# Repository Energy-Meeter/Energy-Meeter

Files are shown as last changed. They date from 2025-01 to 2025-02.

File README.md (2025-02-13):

# Energy Meeter

An esp32-powered smart plug and online dashboard.

## Features

- Online dashboard
- WiFi communication
- Capable of analyzing the power consumption of an arbitrary load
- 5A current rating

## Hardware

### Board Revision A

Status: Testing

The current revision of the energy meeter. We just received it from PCBWay, and we're now in the process of assembling and validating it.

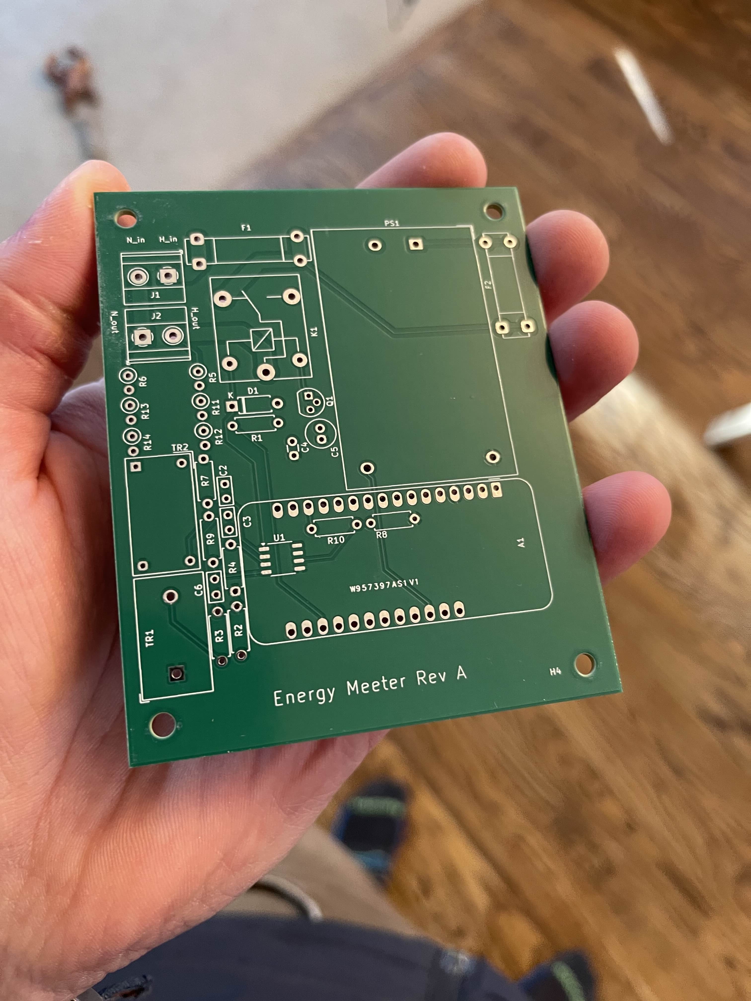
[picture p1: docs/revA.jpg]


#### Schematic
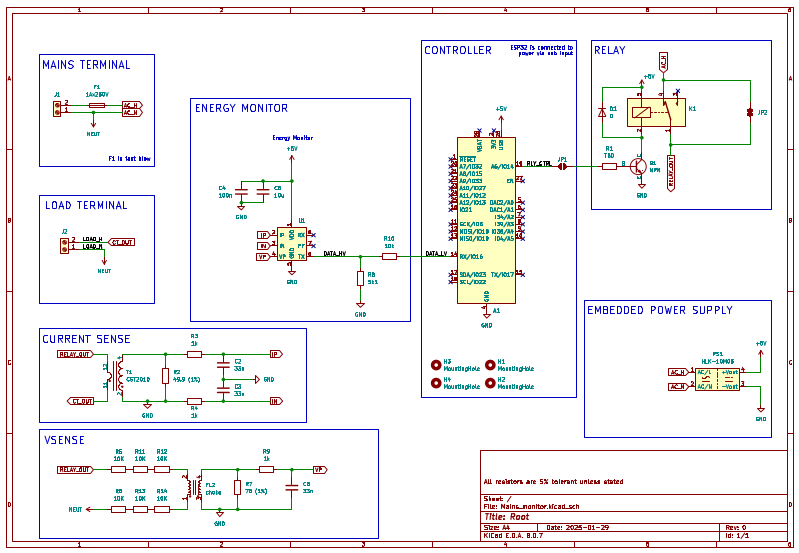
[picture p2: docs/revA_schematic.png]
schmatic


#### Board
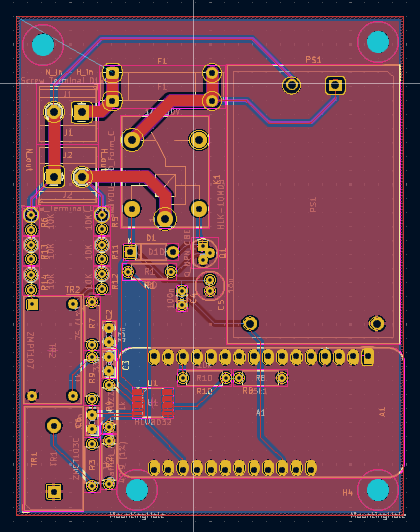
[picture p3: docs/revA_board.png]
board


#### Stack Up
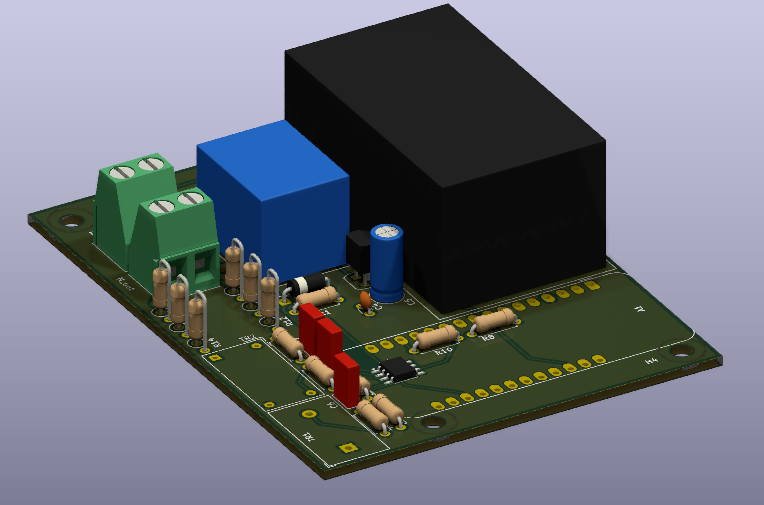
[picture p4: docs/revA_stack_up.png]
Stack up


## Software

### Networking and Dashboard

### Energy Monitor Library

- [HLW8032 energy monitor library](https://github.com/Energy-Meeter/HLW8032)

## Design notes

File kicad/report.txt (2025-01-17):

Plotted to '/home/cullen/Projects/Mains_monitor/kicad/Mains_monitor-energy monitor-Untitled Sheet.svg'.
Info: Done

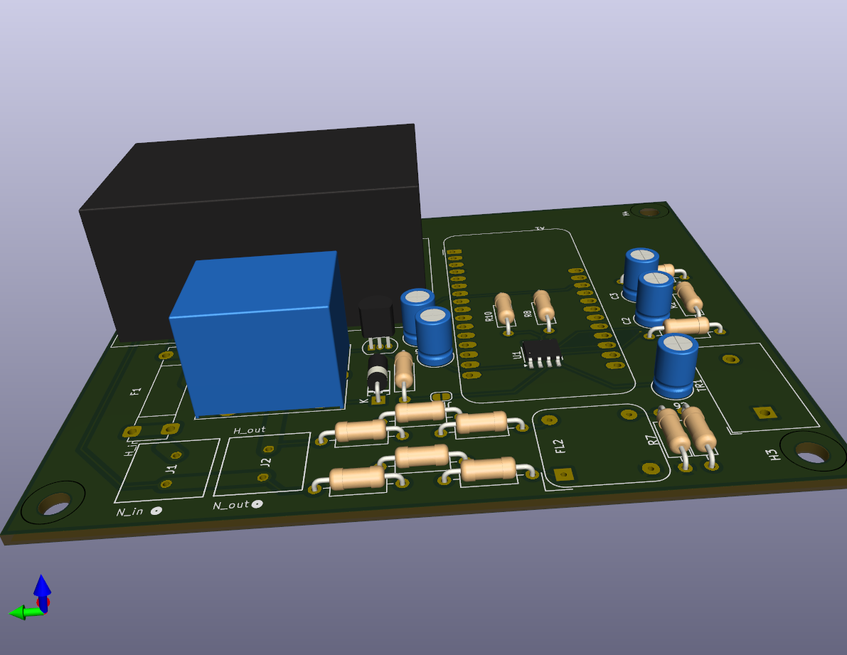
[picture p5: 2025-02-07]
kicad/Mains_monitor.png

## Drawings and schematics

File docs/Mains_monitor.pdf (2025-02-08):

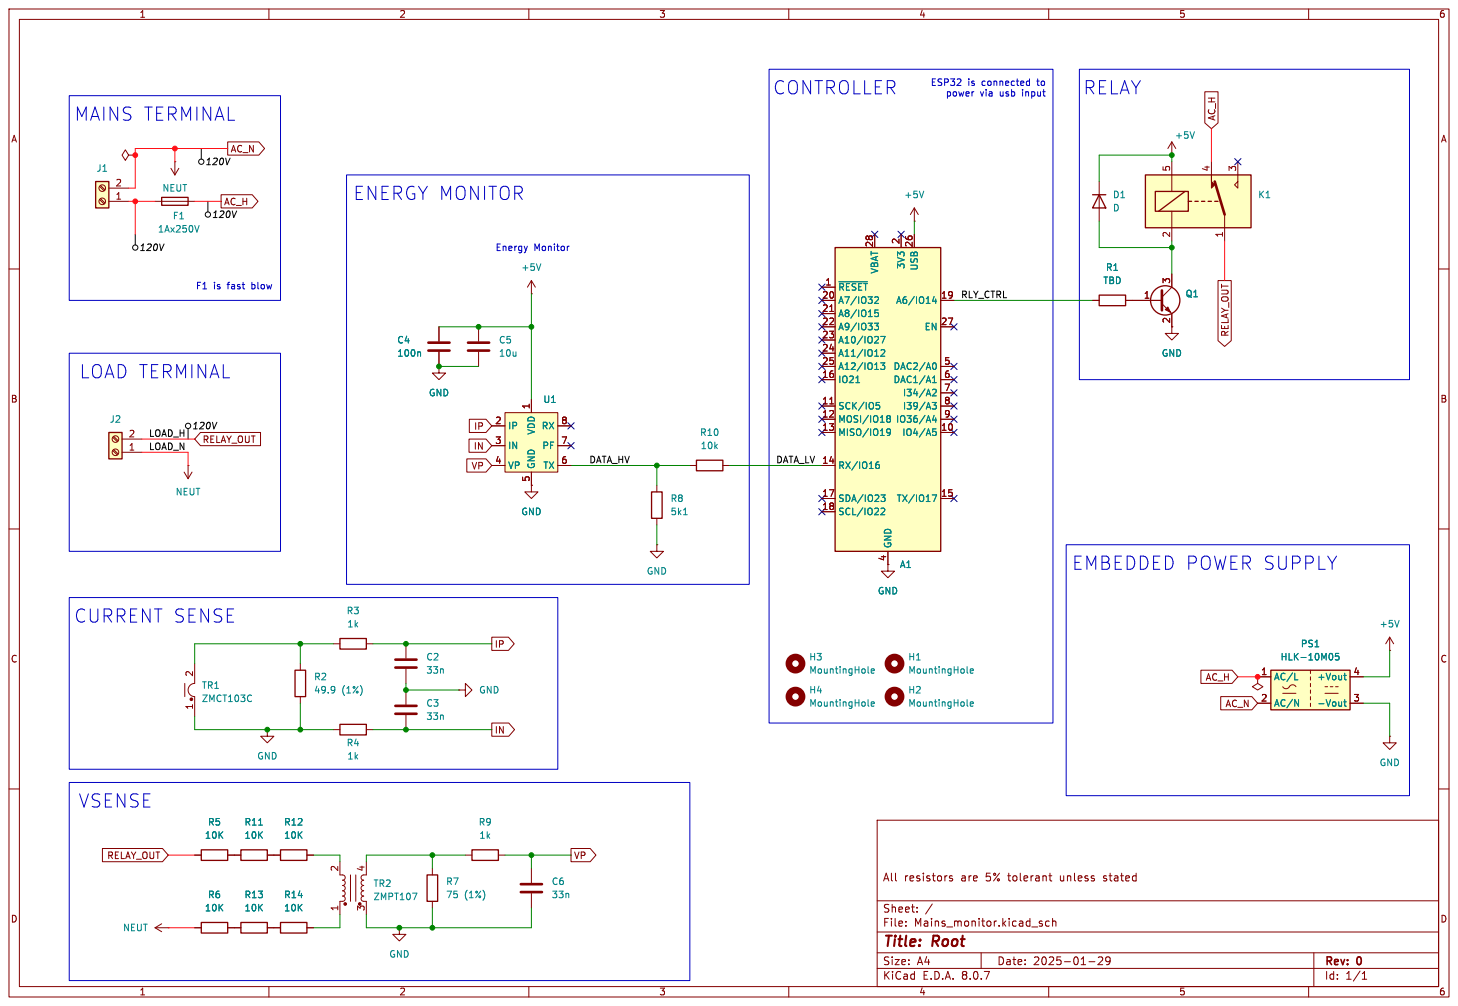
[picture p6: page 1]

power via usb input A1 ~{RESET} 1

2 A7/IO32 20 A8/IO15 21 A9/IO33 22 A10/IO27 23 A11/IO12 24 A12/IO13 25 USB 26 EN 27 VBAT 28 GND

F1 is fast blow LOAD TERMINAL

5 TX 6 PF 7 RX 8 U1 GND

5 TX 6 PF 7 RX 8 PS1 HLK-10M05 AC/L 1 AC/N 2

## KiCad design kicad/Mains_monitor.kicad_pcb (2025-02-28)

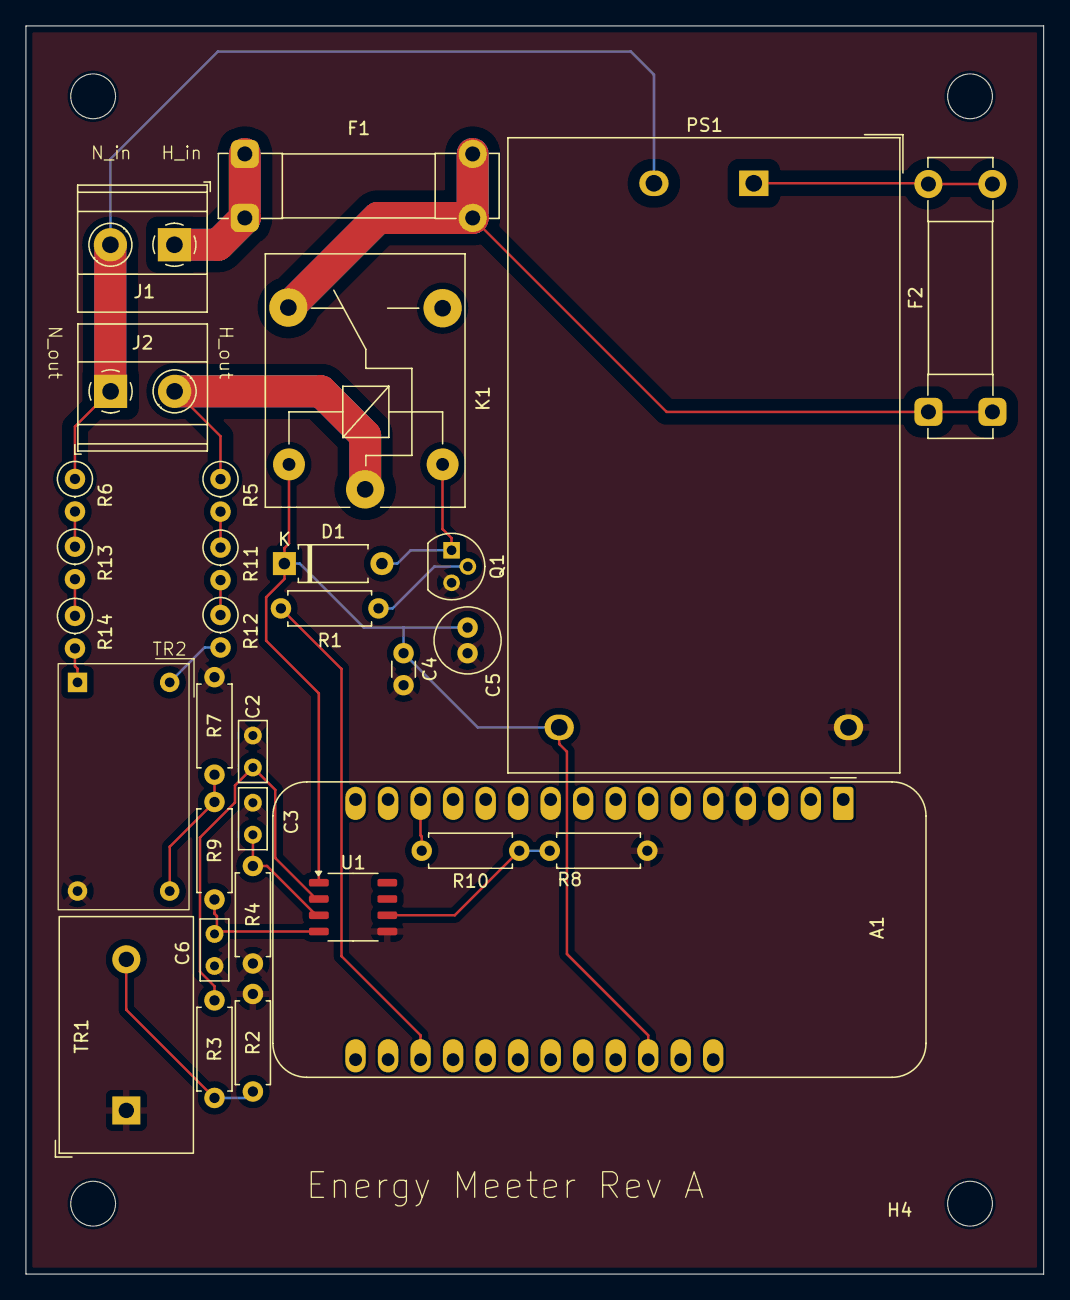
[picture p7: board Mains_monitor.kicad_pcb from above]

Board: 2 copper layers, 79.5 x 97.5 mm, 35 parts (0 on the bottom side), 23 nets.

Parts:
A1: Adafruit_Feather_HUZZAH32_ESP32; Adafruit_Feather
C2, C3, C6: 33n; C_Rect_L4.6mm_W2.0mm_P2.50mm_MKS02_FKP02
C4: 100n; C_Disc_D3.0mm_W1.6mm_P2.50mm
C5: 10u; C_Radial_D5.0mm_H11.0mm_P2.00mm
D1: D; D_A-405_P7.62mm_Horizontal
F1: 1Ax250V; Fuseholder_Clip-5x20mm_Bel_FC-203-22_Lateral_P17.80x5.00mm_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
F2: 100mAx250V; Fuseholder_Clip-5x20mm_Bel_FC-203-22_Lateral_P17.80x5.00mm_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
H1, H2, H3, H4: MountingHole; MountingHole_3.5mm
J1, J2: Screw_Terminal_01x02; TerminalBlock_Phoenix_MKDS-1,5-2_1x02_P5.00mm_Horizontal
K1: SANYOU_SRD_Form_C; Relay_SPDT_SANYOU_SRD_Series_Form_C
PS1: HLK-10M05; Converter_ACDC_Hi-Link_HLK-10Mxx
Q1: Q_NPN_CBE; TO-92
R1: TBD; R_Axial_DIN0207_L6.3mm_D2.5mm_P7.62mm_Horizontal
R2: 49.9 (1%); R_Axial_DIN0207_L6.3mm_D2.5mm_P7.62mm_Horizontal
R3, R4, R9: 1k; R_Axial_DIN0207_L6.3mm_D2.5mm_P7.62mm_Horizontal
R5, R6, R11, R12, R13, R14: 10K; R_Axial_DIN0207_L6.3mm_D2.5mm_P2.54mm_Vertical
R7: 75 (1%); R_Axial_DIN0207_L6.3mm_D2.5mm_P7.62mm_Horizontal
R8: 5k1; R_Axial_DIN0207_L6.3mm_D2.5mm_P7.62mm_Horizontal
R10: 10k; R_Axial_DIN0207_L6.3mm_D2.5mm_P7.62mm_Horizontal
TR1: ZMCT103C; Transformer_Zeming_ZMCT103C
TR2: ZMPT107; ZMPT107-1
U1: HLW8032; SSOP-8_3.9x5.05mm_P1.27mm

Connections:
+5V: A1.26 (USB), C4.1, C5.2, D1.1 (K), K1.5, PS1.4 (+Vout), U1.1 (VDD)
/DATA_HV: R8.1, R10.1, U1.6 (TX)
/DATA_LV: A1.14 (RX/IO16), R10.2
/RLY_CTRL: A1.19 (A6/IO14), R1.1
AC_H: F1.2, F2.1, K1.4
AC_N: J1.2, J2.1, PS1.2 (AC/N), R6.1
GND: A1.4 (GND), C2.2, C3.1, C4.2, C5.1, C6.2, PS1.3 (-Vout), Q1.3 (E), R2.2, R4.1, R7.1, R8.2, TR1.1, TR2.3, U1.5 (GND)
IN: C3.2, R4.2, U1.3 (IN)
IP: C2.1, R3.2, U1.2 (IP)
unnamed: D1.2 (A), K1.2, Q1.1 (C)
unnamed: F1.1, J1.1
unnamed: F2.2, PS1.1 (AC/L)
unnamed: Q1.2 (B), R1.2
unnamed: R2.1, R3.1, TR1.2
unnamed: R7.2, R9.1, TR2.4
unnamed: R5.2, R11.1
unnamed: R11.2, R12.1
unnamed: R12.2, TR2.2
unnamed: R6.2, R13.1
unnamed: R13.2, R14.1
unnamed: R14.2, TR2.1
RELAY_OUT: J2.2, K1.1, R5.1
VP: C6.1, R9.2, U1.4 (VP)

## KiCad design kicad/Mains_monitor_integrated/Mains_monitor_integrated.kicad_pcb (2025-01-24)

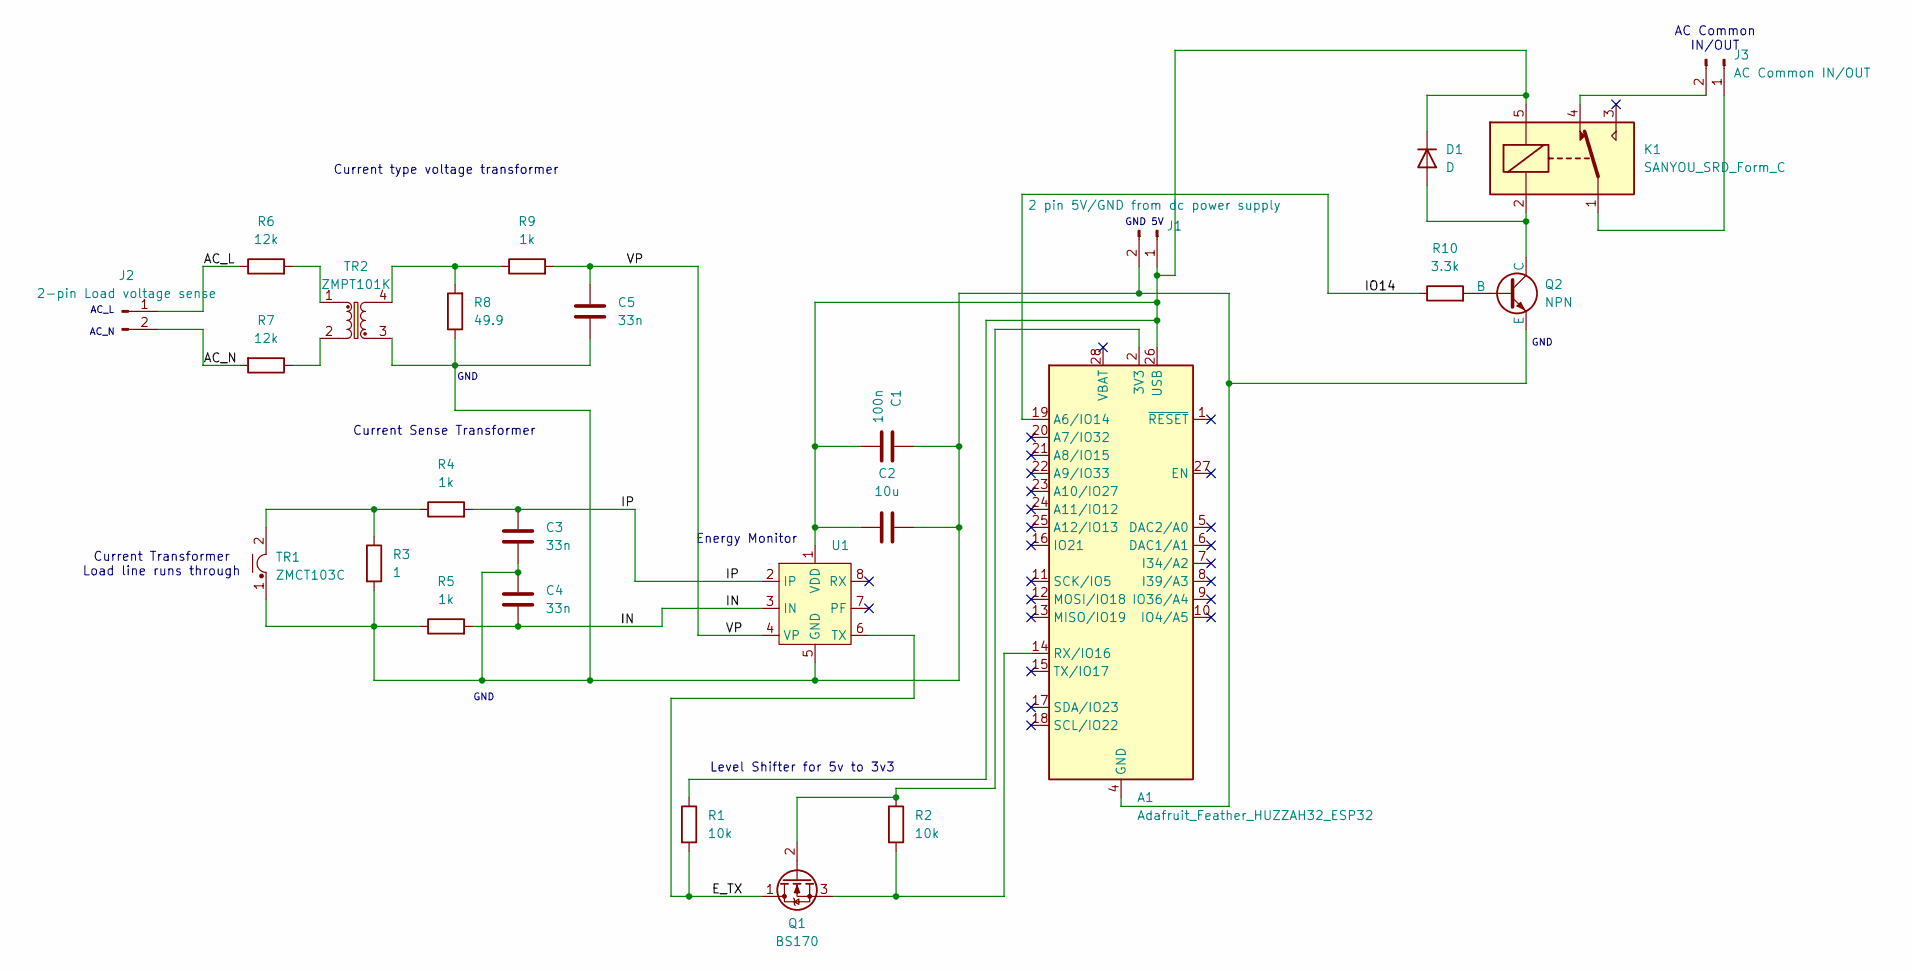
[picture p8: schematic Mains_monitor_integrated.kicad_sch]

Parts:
A1: Adafruit_Feather_HUZZAH32_ESP32; Adafruit_Feather
C1: 100n; C_0805_2012Metric_Pad1.18x1.45mm_HandSolder
C2: 10u; C_0805_2012Metric_Pad1.18x1.45mm_HandSolder
C3, C4, C5: 33n; C_0805_2012Metric_Pad1.18x1.45mm_HandSolder
D1: D; D_5W_P10.16mm_Horizontal
J1: 2 pin 5V/GND from dc power supply; PinSocket_1x02_P2.54mm_Vertical
J2: 2-pin Load voltage sense; PinHeader_1x02_P2.54mm_Vertical
J3: AC Common IN/OUT; PinHeader_1x02_P2.54mm_Vertical
K1: SANYOU_SRD_Form_C; Relay_SPDT_SANYOU_SRD_Series_Form_C
Q1: BS170; TO-92_Inline
Q2: NPN; TO-92_Inline
R1, R2: 10k; R_Axial_DIN0414_L11.9mm_D4.5mm_P5.08mm_Vertical
R3: 1; R_Axial_DIN0414_L11.9mm_D4.5mm_P5.08mm_Vertical
R4, R5, R9: 1k; R_Axial_DIN0414_L11.9mm_D4.5mm_P5.08mm_Vertical
R6, R7: 12k; R_Axial_DIN0414_L11.9mm_D4.5mm_P5.08mm_Vertical
R8: 49.9; R_Axial_DIN0414_L11.9mm_D4.5mm_P5.08mm_Vertical
R10: 3.3k; R_Axial_DIN0414_L11.9mm_D4.5mm_P5.08mm_Vertical
TR1: ZMCT103C; Transformer_Zeming_ZMCT103C
TR2: ZMPT101K; Transformer_Zeming_ZMPT101K
U1: HLW8032; SSOP-8_3.9x5.05mm_P1.27mm

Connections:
/AC_L: J2.1, R6.1
/AC_N: J2.2, R7.2
/E_TX: Q1.1 (D), R1.2, U1.6 (TX)
/IN: C4.2, R5.2, U1.3 (IN)
/IO14: A1.19 (A6/IO14), R10.1
/IP: C3.1, R4.2, U1.2 (IP)
/VP: C5.1, R9.2, U1.4 (VP)
unnamed: A1.2 (3V3), Q1.2 (G), R2.1
unnamed: A1.4 (GND), C1.1, C2.1, C3.2, C4.1, C5.2, J1.2, Q2.3 (E), R3.2, R5.1, R8.1, TR1.1, TR2.3, U1.5 (GND)
unnamed: A1.14 (RX/IO16), Q1.3 (S), R2.2
unnamed: A1.26 (USB), C1.2, C2.2, D1.1 (K), J1.1, K1.5, R1.1, U1.1 (VDD)
unnamed: D1.2 (A), K1.2, Q2.1 (C)
unnamed: J3.1, K1.1
unnamed: J3.2, K1.4
unnamed: Q2.2 (B), R10.2
unnamed: R3.1, R4.1, TR1.2
unnamed: R6.2, TR2.1
unnamed: R7.1, TR2.2
unnamed: R8.2, R9.1, TR2.4

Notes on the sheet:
GND
AC_L AC_N
Level Shifter for 5v to 3v3
AC Common IN/OUT
Current Sense Transformer
GND 5V
Current type voltage transformer
Energy Monitor
Current Transformer Load line runs through

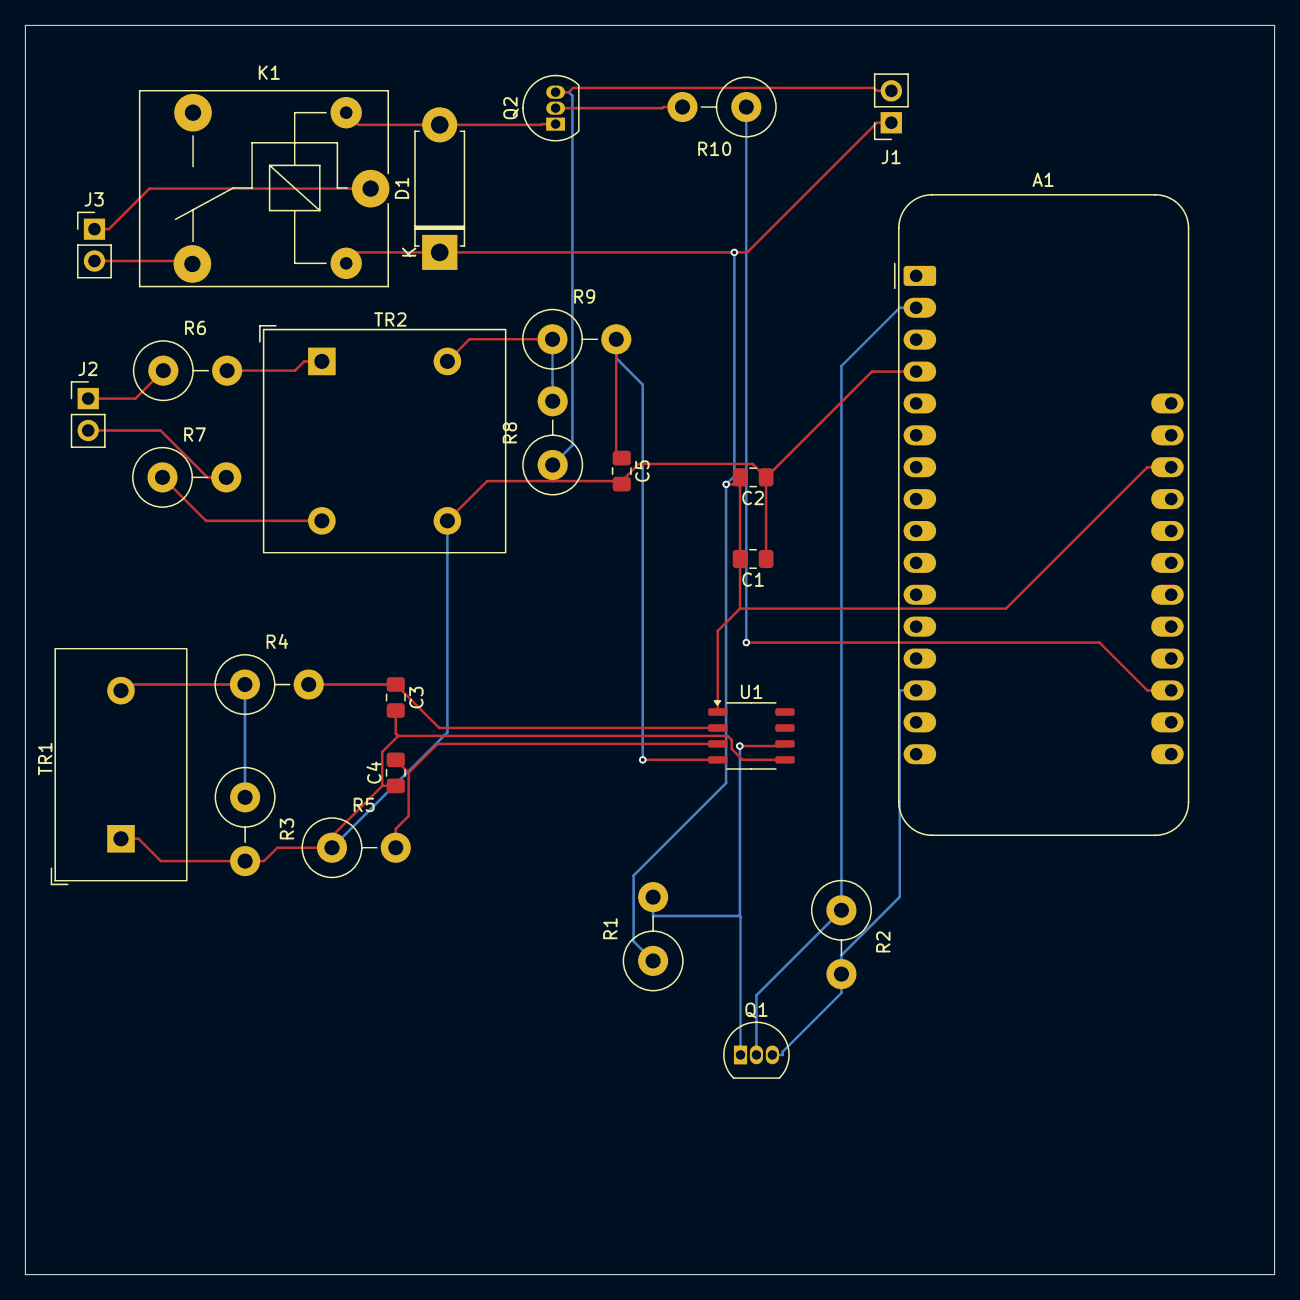
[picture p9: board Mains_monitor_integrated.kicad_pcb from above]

Board: 2 copper layers, 99.5 x 99.5 mm, 26 parts (0 on the bottom side), 19 nets.

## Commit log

2025-01-01 Init commit
    [Mains_monitor.kicad_pcb, Mains_monitor.kicad_sch, energy_monitor.kicad_sch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]
2025-01-01 Design power supply circuit
    [Mains_monitor.kicad_sch, current_sense_ckt.kicad_sch, energy_monitor.kicad_sch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]
2025-01-17 Add rev0 schematic
    [current_sense_ckt.kicad_sch, energy_monitor.kicad_sch, isolated supply.kicad_sch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]
2025-01-17 Add pdf of rev0 schematic
2025-01-19 Add git ignore for KiCad Projectt
2025-01-19 Consolidate schematic to a single sheet
    [current_sense_ckt.kicad_sch, energy_monitor.kicad_sch, isolated supply.kicad_sch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]
2025-01-24 created new schematic to integrate all components into a fully connected final version
    [Mains_monitor_integrated.kicad_pcb, Mains_monitor_integrated.kicad_sch]
2025-01-24 completed rough schematic and built first prototype pcb
    [Mains_monitor_integrated.kicad_pcb, Mains_monitor_integrated.kicad_sch]
2025-01-31 Improve sch clarity
    [Mains_monitor.kicad_sch]
2025-02-03 added footprints for all components, started PCB layout
    [Mains_monitor.kicad_pcb, Mains_monitor.kicad_sch]
2025-02-03 added mounting holes and ground layers
    [Mains_monitor.kicad_pcb, Mains_monitor.kicad_sch]
2025-02-04 PCB layout updated, traces and base fill added, still need to make space for mounting holes
    [Mains_monitor.kicad_pcb, Mains_monitor.kicad_sch]
2025-02-05 added net class for 120V and mounting holes
    [Mains_monitor.kicad_pcb, Mains_monitor.kicad_sch]
2025-02-05 backup files
    [Mains_monitor.kicad_pcb]
2025-02-06 Update footprints and git ignore
    [Mains_monitor.kicad_sch]
2025-02-06 Get footprint from main
2025-02-06 Added in the correct footprints
    [Mains_monitor.kicad_sch]
2025-02-06 Updated PCB layout with new components, decreased board size
    [Mains_monitor.kicad_pcb]
2025-02-06 added updated screw terminal footprints
    [Mains_monitor.kicad_pcb, Mains_monitor.kicad_sch]
2025-02-07 Clear ERC, and change Q1
    [Mains_monitor.kicad_sch]
2025-02-07 Clear DRC
    [Mains_monitor.kicad_pcb]
2025-02-07 Plot gerbers/drill
    [Mains_monitor-B_Cu.gbr, Mains_monitor-B_Mask.gbr, Mains_monitor-B_Paste.gbr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]
2025-02-07 Add png schematic to add to README
2025-02-07 updated electrical spacing
    [Mains_monitor.kicad_pcb]
2025-02-07 added power supply fuse, increased high current trace size, Ready to order
    [Mains_monitor.kicad_pcb, Mains_monitor.kicad_sch]
2025-02-07 Added 'Energy Meeter Rev A' to silkscreen
    [Mains_monitor.kicad_pcb]
2025-02-13 Add pictures of unpopulated PCB
